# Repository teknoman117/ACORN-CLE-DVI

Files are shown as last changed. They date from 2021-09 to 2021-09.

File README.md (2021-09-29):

# ACORN-CLE-DVI

Add DVI support to the Acorn CLE-215(+)/101 by using a PI3HDX511D DisplayPort Level Shifter / TMDS Redriver.

The NiteFury, LiteFury, and Acorn CLE-215(+)/101 IO connector has 4x LVDS pairs (2.5V VCCO) and 2x 3.3V differential pairs for a total of 12 IO pins. Since HDMI/DVI requires 4 differential pairs (3 color, 1 clock), we need more 3.3V IO pins than are available. DisplayPort uses LVDS, so there are chips on the market for GPUs and smartphones so that only a single electrical standard is required to be implemented by the ASIC, and an external driver IC can be used.

A boost converter is also present to step the 3.3V supply on the IO connector to 5V to output to the HDMI/DVI sink.

### License

CC-BY-SA 4.0

### Pictures

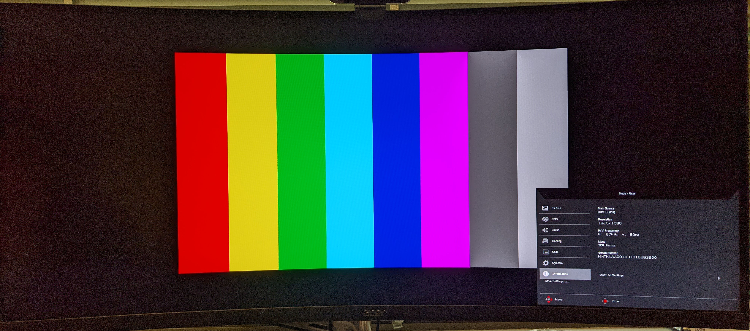
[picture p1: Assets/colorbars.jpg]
Colorbars

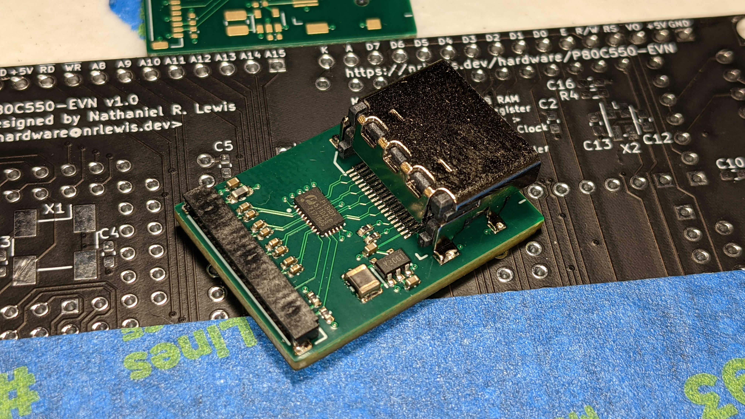
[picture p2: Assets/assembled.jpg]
Assembled

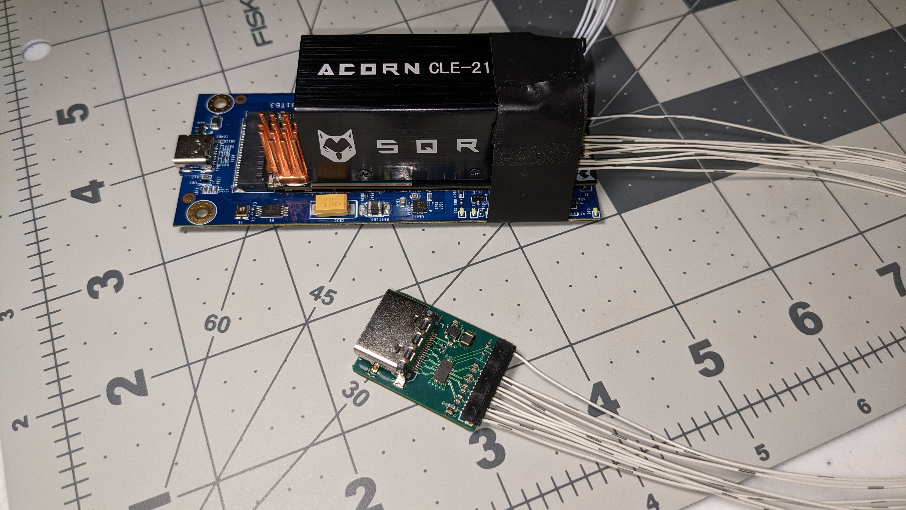
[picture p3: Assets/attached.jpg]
Attached


### Schematic

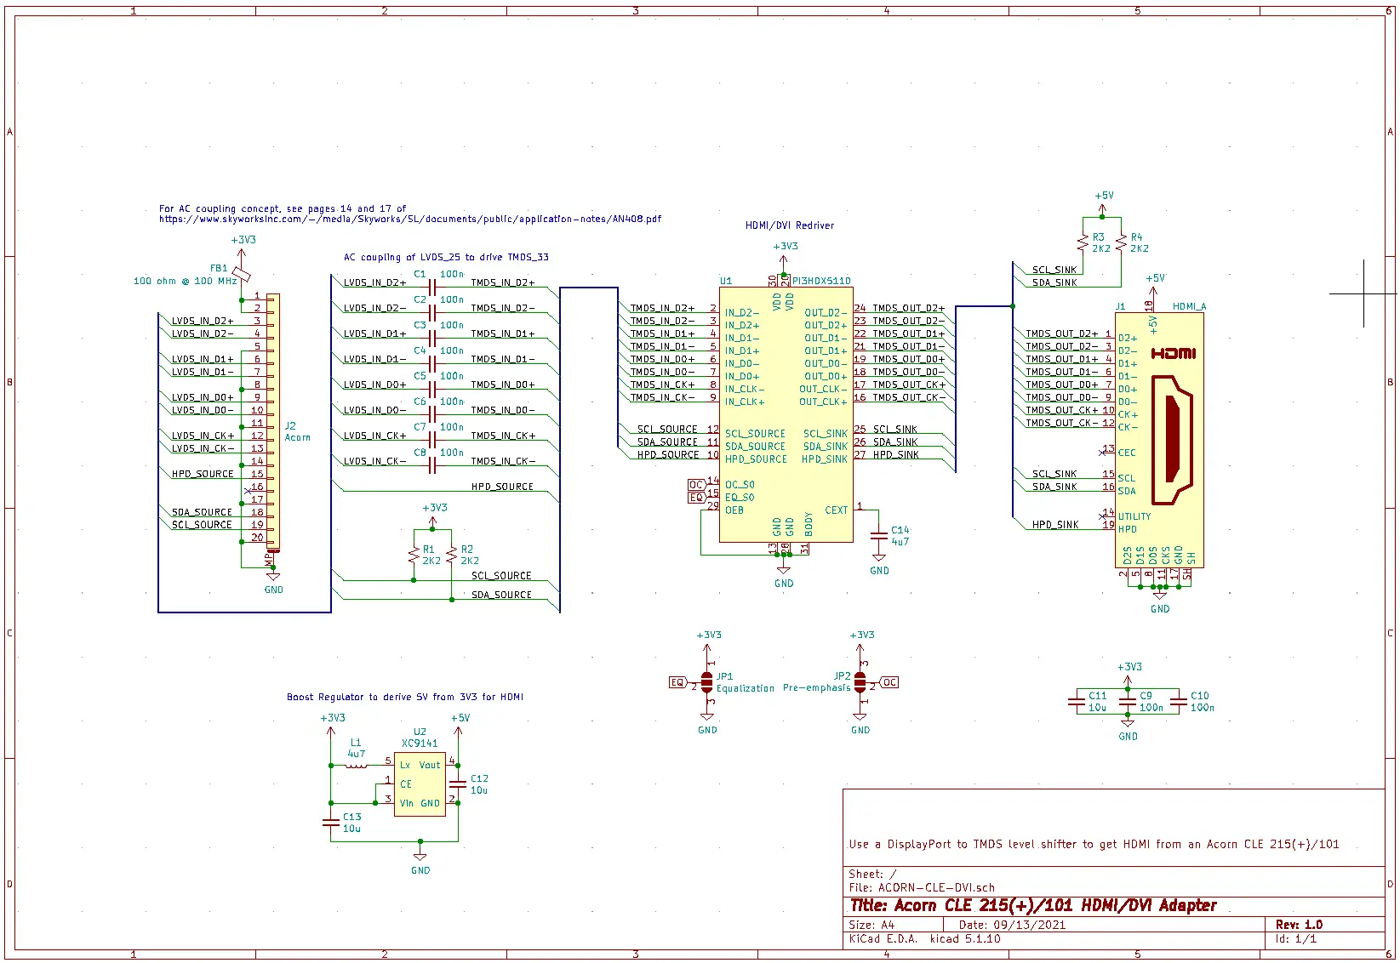
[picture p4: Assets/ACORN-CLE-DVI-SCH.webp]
Schematic


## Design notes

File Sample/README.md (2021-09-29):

# Sample Project

A sample HDL project for the Acorn CLE-215+ to generate 1080p60 with the ACORN-CLE-DVI adapter

# License

MIT

The overwhelming majority of the code is from https://github.com/projf/display_controller that I wrapped as a Vivado project.

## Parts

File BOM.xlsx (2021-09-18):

Reference | Quantity | Value | Footprint | Datasheet | Digikey_Link | Digikey_PN
C1 C2 C3 C4 C5 C6 C7 C8 C9 C10 | 10 | 100n | Capacitor_SMD:C_0402_1005Metric | https://media.digikey.com/pdf/Data%20Sheets/Samsung%20PDFs/CL05A104KA5NNNC.pdf | https://www.digikey.com/en/products/detail/samsung-electro-mechanics/CL05A104KA5NNNC/3886701 | 1276-1043-2-ND
C11 C12 C13 | 3 | 10u | Capacitor_SMD:C_0402_1005Metric | https://www.murata.com/-/media/webrenewal/support/library/catalog/products/capacitor/ceramiccapacitor/c02e.ashx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 | https://www.digikey.com/en/products/detail/murata-electronics/GRM155R61A106ME11D/12091056 | 490-GRM155R61A106ME11DTR-ND
C14 | 1 | 4u7 | Capacitor_SMD:C_0402_1005Metric | http://www.samsungsem.com/kr/support/product-search/mlcc/CL05A475MP5NRNC.jsp | https://www.digikey.com/en/products/detail/samsung-electro-mechanics/CL05A475MP5NRNC/3887140 | 1276-1482-2-ND
FB1 | 1 | 100 ohm @ 100 MHz | Inductor_SMD:L_0603_1608Metric | https://media.digikey.com/pdf/Data%20Sheets/Murata%20PDFs/BLM18yyyyyyN1x.pdf | https://www.digikey.com/en/products/detail/murata-electronics/BLM18KG101TN1D/2260753 | 490-5448-2-ND
J1 | 1 | HDMI_A | Digikey:HDMI_A_Female_2000-1-2-41-00-BK | http://www.cnctech.us/pdfs/2000-1-2-41-00-BK.pdf | https://www.digikey.com/en/products/detail/cnc-tech/2000-1-2-41-00-BK/4867012 | 1175-1703-ND
J2 | 1 | Acorn | ACORN-CLE-HDMI:Hirose_DF52-20S-0.8H_1x20-1MP_P0.80mm_Horizontal | https://www.hirose.com/product/document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 | https://www.digikey.com/en/products/detail/hirose-electric-co-ltd/DF52-20S-0-8H-21/5721363 | H125108TR-ND
L1 | 1 | 4u7 | Inductor_SMD:L_1008_2520Metric | https://abracon.com/Magnetics/inductors/AIML-1008HC.pdf | https://www.digikey.com/en/products/detail/abracon-llc/AIML-1008HC-4R7M-T/5043494 | 535-12797-2-ND
R1 R2 R3 R4 | 4 | 2K2 | Resistor_SMD:R_0402_1005Metric | https://www.yageo.com/upload/media/product/productsearch/datasheet/rchip/PYu-RC_Group_51_RoHS_L_11.pdf | https://www.digikey.com/en/products/detail/yageo/RC0402JR-072K2L/726436 | 311-2.2KJRTR-ND
U1 | 1 | PI3HDX511D | ACORN-CLE-HDMI:TQFN-30 | https://www.mouser.com/datasheet/2/115/diodes_inc_diod-s-a0004145302-1-1749206.pdf | https://www.digikey.com/en/products/detail/diodes-incorporated/PI3HDX511DZLEX/6237527 | PI3HDX511DZLEXDITR-ND
U2 | 1 | XC9141 | Package_TO_SOT_SMD:SOT-23-5 | https://www.torexsemi.com/file/xc9141/XC9141-XC9142.pdf | https://www.digikey.com/en/products/detail/torex-semiconductor-ltd/XC9141B50CMR-G/6148745 | 893-1369-2-ND

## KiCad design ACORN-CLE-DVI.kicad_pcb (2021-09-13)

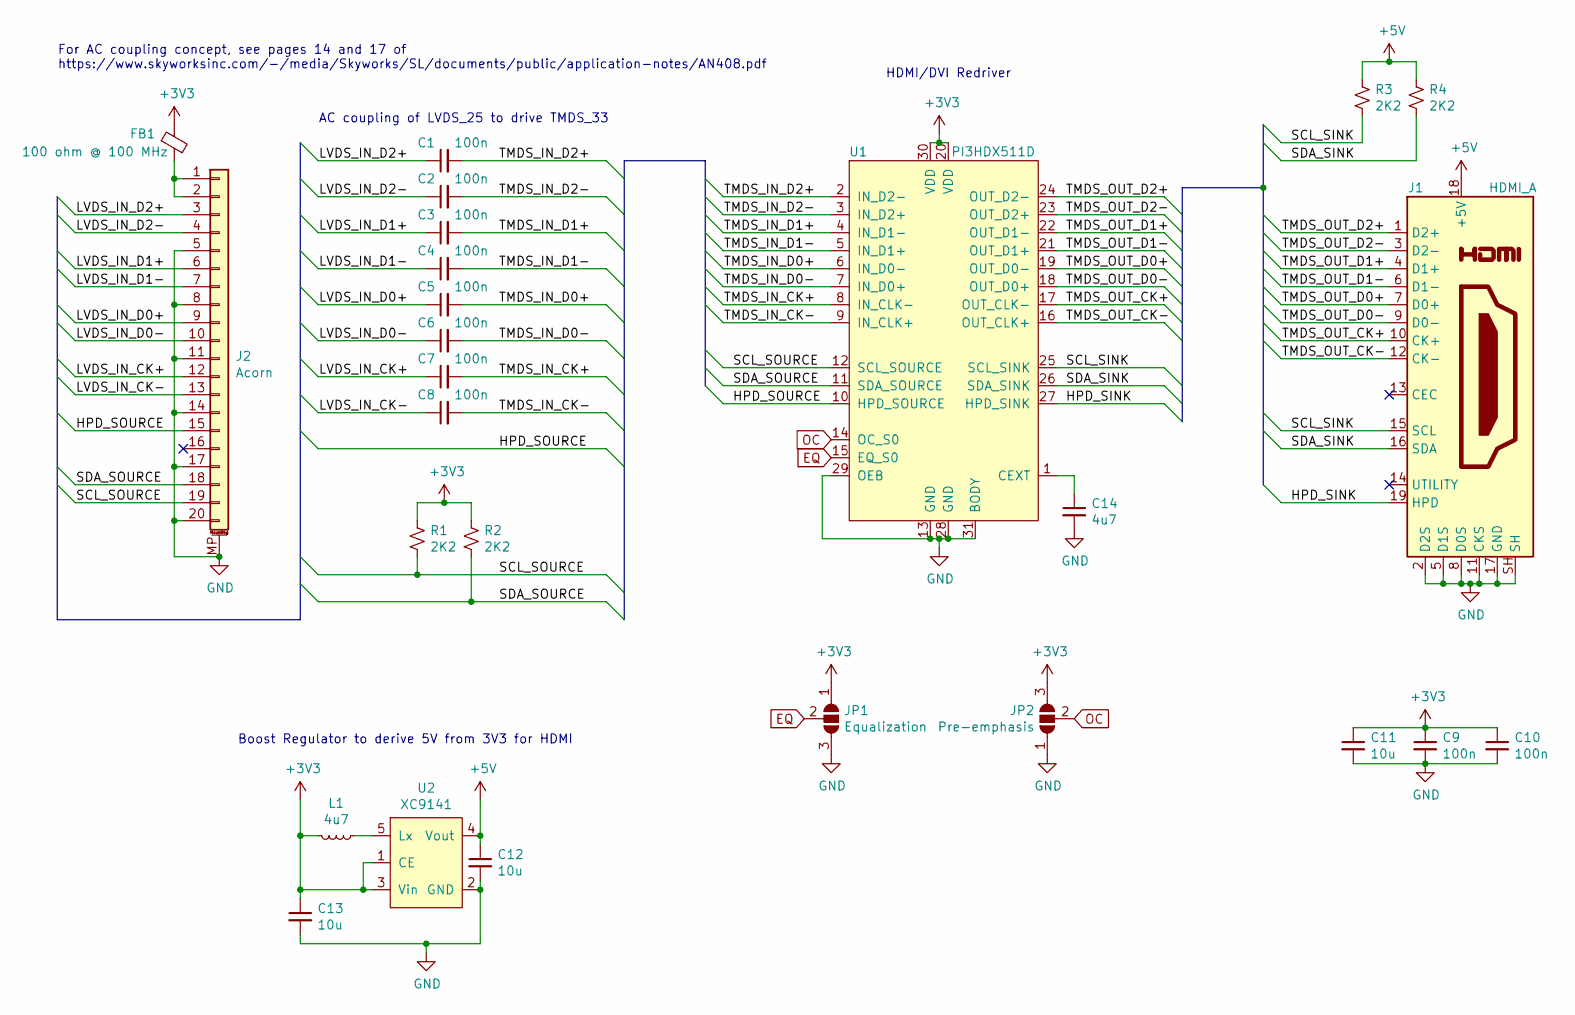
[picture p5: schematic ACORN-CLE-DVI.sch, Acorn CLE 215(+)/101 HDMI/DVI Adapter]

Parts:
C1, C2, C3, C4, C5, C6, C7, C8, C9, C10: 100n; C_0402_1005Metric; Digikey_PN 1276-1043-2-ND
C11, C12, C13: 10u; C_0402_1005Metric; Digikey_PN 490-GRM155R61A106ME11DTR-ND
C14: 4u7; C_0402_1005Metric; Digikey_PN 1276-1482-2-ND
FB1: 100 ohm @ 100 MHz; L_0603_1608Metric; Digikey_PN 490-5448-2-ND
J1: HDMI_A; HDMI_A_Female_2000-1-2-41-00-BK; Digikey_PN 1175-1703-ND
J2: Acorn; Hirose_DF52-20S-0.8H_1x20-1MP_P0.80mm_Horizontal; Digikey_PN H125108TR-ND
JP1: Equalization; SolderJumper-3_P1.3mm_Open_RoundedPad1.0x1.5mm_NumberLabels
JP2: Pre-emphasis; SolderJumper-3_P1.3mm_Open_RoundedPad1.0x1.5mm_NumberLabels
L1: 4u7; L_1008_2520Metric; Digikey_PN 535-12797-2-ND
R1, R2, R3, R4: 2K2; R_0402_1005Metric; Digikey_PN 311-2.2KJRTR-ND
U1: PI3HDX511D; TQFN-30; Digikey_PN PI3HDX511DZLEXDITR-ND
U2: XC9141; SOT-23-5; Digikey_PN 893-1369-2-ND

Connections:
+3V3: C9.1, C10.1, C11.1, C13.1, FB1.1, JP1.1 (A), JP2.3 (B), L1.2, R1.1, R2.1, U1.20 (VDD), U1.30 (VDD), U2.1 (CE), U2.3 (Vin)
+5V: C12.1, J1.18 (+5V), R3.1, R4.1, U2.4 (Vout)
/HPD_SINK: J1.19 (HPD), U1.27 (HPD_SINK)
/HPD_SOURCE: J2.15, U1.10 (HPD_SOURCE)
/LVDS_IN_CK+: C7.1, J2.12
/LVDS_IN_CK-: C8.1, J2.13
/LVDS_IN_D0+: C5.1, J2.9
/LVDS_IN_D0-: C6.1, J2.10
/LVDS_IN_D1+: C3.1, J2.6
/LVDS_IN_D1-: C4.1, J2.7
/LVDS_IN_D2+: C1.1, J2.3
/LVDS_IN_D2-: C2.1, J2.4
/SCL_SINK: J1.15 (SCL), R3.2, U1.25 (SCL_SINK)
/SCL_SOURCE: J2.19, R1.2, U1.12 (SCL_SOURCE)
/SDA_SINK: J1.16 (SDA), R4.2, U1.26 (SDA_SINK)
/SDA_SOURCE: J2.18, R2.2, U1.11 (SDA_SOURCE)
/TMDS_IN_CK+: C7.2, U1.8 (IN_CLK-)
/TMDS_IN_CK-: C8.2, U1.9 (IN_CLK+)
/TMDS_IN_D0+: C5.2, U1.6 (IN_D0-)
/TMDS_IN_D0-: C6.2, U1.7 (IN_D0+)
/TMDS_IN_D1+: C3.2, U1.4 (IN_D1-)
/TMDS_IN_D1-: C4.2, U1.5 (IN_D1+)
/TMDS_IN_D2+: C1.2, U1.2 (IN_D2-)
/TMDS_IN_D2-: C2.2, U1.3 (IN_D2+)
/TMDS_OUT_CK+: J1.10 (CK+), U1.17 (OUT_CLK-)
/TMDS_OUT_CK-: J1.12 (CK-), U1.16 (OUT_CLK+)
/TMDS_OUT_D0+: J1.7 (D0+), U1.19 (OUT_D0-)
/TMDS_OUT_D0-: J1.9 (D0-), U1.18 (OUT_D0+)
/TMDS_OUT_D1+: J1.4 (D1+), U1.22 (OUT_D1-)
/TMDS_OUT_D1-: J1.6 (D1-), U1.21 (OUT_D1+)
/TMDS_OUT_D2+: J1.1 (D2+), U1.24 (OUT_D2-)
/TMDS_OUT_D2-: J1.3 (D2-), U1.23 (OUT_D2+)
EQ: JP1.2 (C), U1.15 (EQ_S0)
GND: C9.2, C10.2, C11.2, C12.2, C13.2, C14.2, J1.2 (D2S), J1.5 (D1S), J1.8 (D0S), J1.11 (CKS), J1.17 (GND), J1.SH, J2.5, J2.8, J2.11, J2.14, J2.17, J2.20, J2.MP (MountPin), JP1.3 (B), JP2.1 (A), U1.13 (GND), U1.28 (GND), U1.29 (OEB), U1.31 (BODY), U2.2 (GND)
unnamed: C14.1, U1.1 (CEXT)
unnamed: FB1.2, J2.1, J2.2
unnamed: L1.1, U2.5 (Lx)
OC: JP2.2 (C), U1.14 (OC_S0)

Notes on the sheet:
AC coupling of LVDS_25 to drive TMDS_33
For AC coupling concept, see pages 14 and 17 of https://www.skyworksinc.com/-/media/Skyworks/SL/documents/public/application-notes/AN408.pdf
HDMI/DVI Redriver
Boost Regulator to derive 5V from 3V3 for HDMI

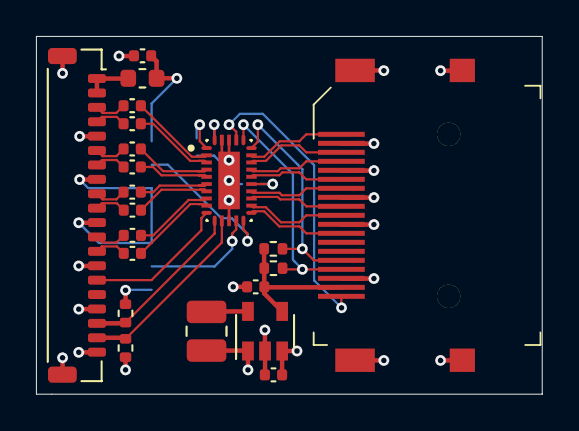
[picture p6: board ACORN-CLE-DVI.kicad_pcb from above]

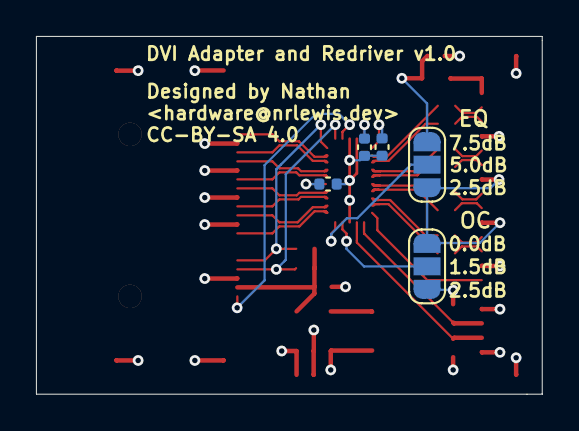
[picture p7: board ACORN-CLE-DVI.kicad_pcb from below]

Board: 4 copper layers, 28.1 x 19.9 mm, 26 parts (5 on the bottom side), 38 nets.

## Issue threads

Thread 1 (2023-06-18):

What other adapters. use-cases could be imagined leveraging the I/O connector with 4 x LVDS ?

ohault, 2023-06-18:
e.g.
- connecting to a PCIe switch IC or appliance?
- OCuLink adapter
- PCIe rise board using a USB3 cable (PCIe sniffer)
- PCIe pcb connector to plug into a PCIe connector of another host (PCIe interconnect/NTB)

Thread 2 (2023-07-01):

Where did you get the thunderbolt board?

likaigelikaige, 2023-07-01:
RT, it's pleased to give more information about the thunderbolt board, thanks a lot.

teknoman117, 2023-07-01:
It's a Sabrent thunderbolt 3 M.2 enclosure I got from Amazon. Note that it is only a 2-lane PCIe 3.0 interface so the PCIe interface is limited to 1 GB/s.

https://www.amazon.com/gp/product/B08FT59SB6

Closed 2023-07-01.

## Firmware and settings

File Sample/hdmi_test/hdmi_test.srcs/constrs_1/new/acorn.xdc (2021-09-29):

# clk200:0.p
set_property LOC J19 [get_ports {clk_p}]
set_property IOSTANDARD LVDS_25 [get_ports {clk_p}]

create_clock -period 5.000 -name clk_p [get_ports {clk_p}]

# clk200:0.n
set_property LOC H19 [get_ports {clk_n}]
set_property IOSTANDARD LVDS_25 [get_ports {clk_n}]

set_property PACKAGE_PIN G3 [get_ports LED[0]]
set_property IOSTANDARD LVCMOS33 [get_ports {LED[0]}]
set_property PULLUP true [get_ports {LED[0]}]
set_property DRIVE 8 [get_ports {LED[0]}]

set_property PACKAGE_PIN H3 [get_ports {LED[1]}]
set_property IOSTANDARD LVCMOS33 [get_ports {LED[1]}]
set_property PULLUP true [get_ports {LED[1]}]
set_property DRIVE 8 [get_ports {LED[1]}]

set_property PACKAGE_PIN G4 [get_ports {LED[2]}]
set_property IOSTANDARD LVCMOS33 [get_ports {LED[2]}]
set_property PULLUP true [get_ports {LED[2]}]
set_property DRIVE 8 [get_ports {LED[2]}]

set_property PACKAGE_PIN H4 [get_ports {LED[3]}]
set_property IOSTANDARD LVCMOS33 [get_ports {LED[3]}]
set_property PULLUP true [get_ports {LED[3]}]
set_property DRIVE 8 [get_ports {LED[3]}]

# pcie_x4:0.rst_n
set_property LOC J1 [get_ports {RST_BTN}]
set_property IOSTANDARD LVCMOS33 [get_ports {RST_BTN}]
set_property PULLUP TRUE [get_ports {RST_BTN}]

# hdmi:0.clk_p
set_property LOC V9 [get_ports {hdmi_tx_clk_p}]
set_property IOSTANDARD LVDS_25 [get_ports {hdmi_tx_clk_p}]

# hdmi:0.clk_n
set_property LOC V8 [get_ports {hdmi_tx_clk_n}]
set_property IOSTANDARD LVDS_25 [get_ports {hdmi_tx_clk_n}]

# hdmi:0.data0_p
set_property LOC Y8 [get_ports {hdmi_tx_p[0]}]
set_property IOSTANDARD LVDS_25 [get_ports {hdmi_tx_p[0]}]

# hdmi:0.data0_n
set_property LOC Y7 [get_ports {hdmi_tx_n[0]}]
set_property IOSTANDARD LVDS_25 [get_ports {hdmi_tx_n[0]}]

# hdmi:0.data1_p
set_property LOC W9 [get_ports {hdmi_tx_p[1]}]
set_property IOSTANDARD LVDS_25 [get_ports {hdmi_tx_p[1]}]

# hdmi:0.data1_n
set_property LOC Y9 [get_ports {hdmi_tx_n[1]}]
set_property IOSTANDARD LVDS_25 [get_ports {hdmi_tx_n[1]}]

# hdmi:0.data2_p
set_property LOC AA8 [get_ports {hdmi_tx_p[2]}]
set_property IOSTANDARD LVDS_25 [get_ports {hdmi_tx_p[2]}]

# hdmi:0.data2_n
set_property LOC AB8 [get_ports {hdmi_tx_n[2]}]
set_property IOSTANDARD LVDS_25 [get_ports {hdmi_tx_n[2]}]

# High-speed configuration so FPGA is up in time to negotiate with PCIe root complex
set_property BITSTREAM.CONFIG.EXTMASTERCCLK_EN Div-1 [current_design]
set_property BITSTREAM.CONFIG.SPI_BUSWIDTH 4 [current_design]
set_property CONFIG_MODE SPIx4 [current_design]
set_property BITSTREAM.CONFIG.SPI_FALL_EDGE YES [current_design]
set_property BITSTREAM.GENERAL.COMPRESS TRUE [current_design]

set_property CONFIG_VOLTAGE 3.3 [current_design]
set_property CFGBVS VCCO [current_design]

# The default image is an "update" image- can run bare or as part of a multiboot
# Just need to enable this for an update image
set_property BITSTREAM.CONFIG.CONFIGFALLBACK ENABLE [current_design]

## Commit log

2021-09-10 first commit, why are differential signals so damn stupid
    [ACORN-CLE-DVI.kicad_pcb, ACORN-CLE-DVI.sch]
2021-09-10 routed differential pairs
    [ACORN-CLE-DVI.kicad_pcb]
2021-09-11 schematic done, most of board routing
    [ACORN-CLE-DVI-B_Cu.gbl, ACORN-CLE-DVI-B_Mask.gbs, ACORN-CLE-DVI-B_Paste.gbp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]
2021-09-12 functionally complete, need to verify before buying
    [ACORN-CLE-DVI-B_Cu.gbl, ACORN-CLE-DVI-B_Mask.gbs, ACORN-CLE-DVI-B_Paste.gbp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]
2021-09-13 add datasheets and digikey part numbers
    [ACORN-CLE-DVI.kicad_pcb, ACORN-CLE-DVI.sch]
2021-09-13 correct the size of the TQFN-30 footprint
    [ACORN-CLE-DVI-B_Cu.gbl, ACORN-CLE-DVI-B_Mask.gbs, ACORN-CLE-DVI-B_Paste.gbp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]
2021-09-13 state at manufacturing
    [ACORN-CLE-DVI-B_Cu.gbl, ACORN-CLE-DVI-B_Mask.gbs, ACORN-CLE-DVI-B_Paste.gbp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]
2021-09-18 add schematic picture
    [ACORN-CLE-DVI.sch, BOM.xlsx]
2021-09-29 add pictured of assembled board
2021-09-29 add sample vivado project
